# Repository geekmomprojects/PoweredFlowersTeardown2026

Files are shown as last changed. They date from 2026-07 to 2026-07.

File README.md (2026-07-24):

# PoweredFlowersTeardown2026

Instructions for the BedazzLED Wearables workshop at Teardown 2026

 

## Hot Glue LED string layout

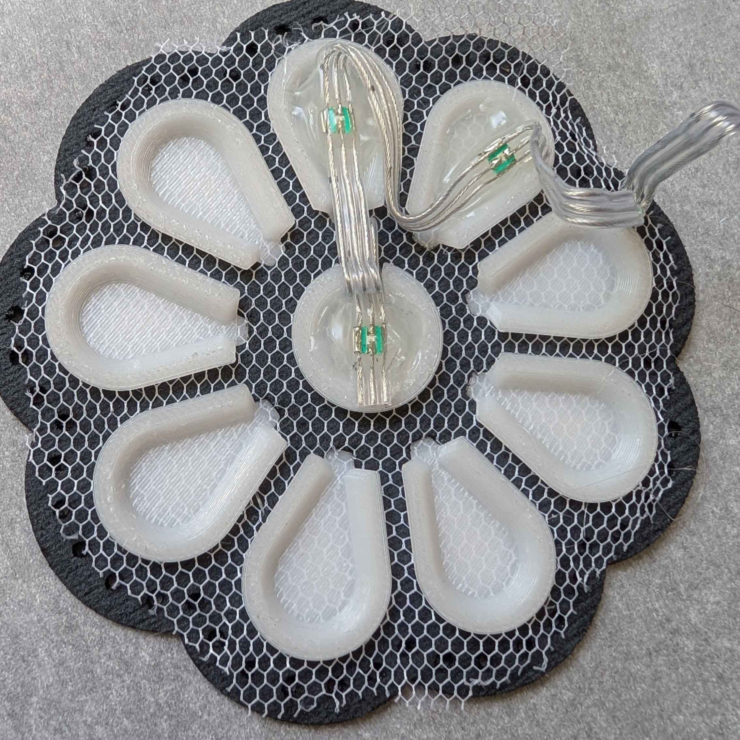
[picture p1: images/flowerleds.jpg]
 <br><br>
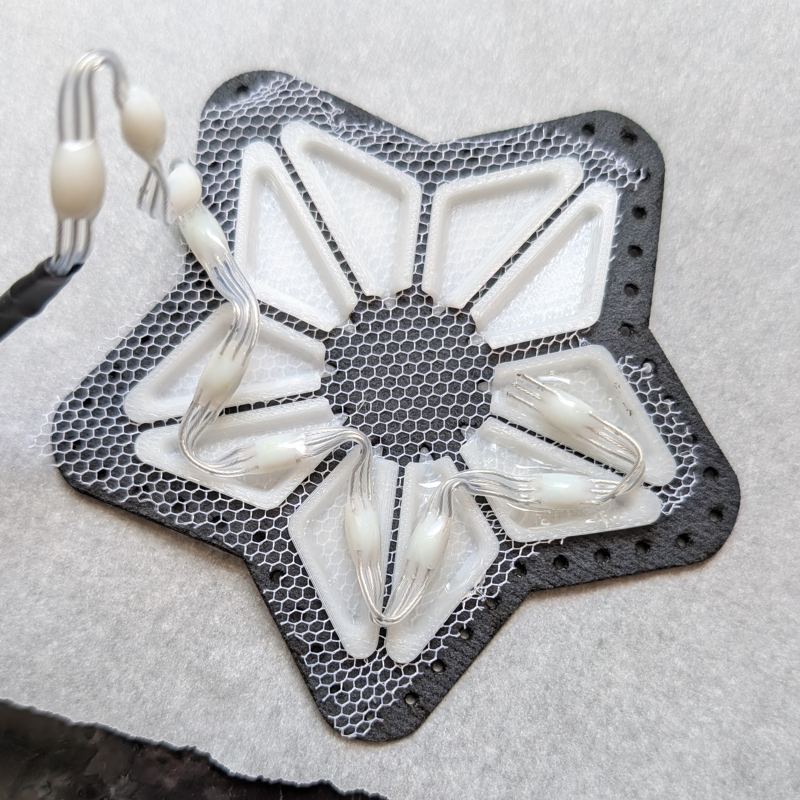
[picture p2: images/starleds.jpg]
 <br><br>
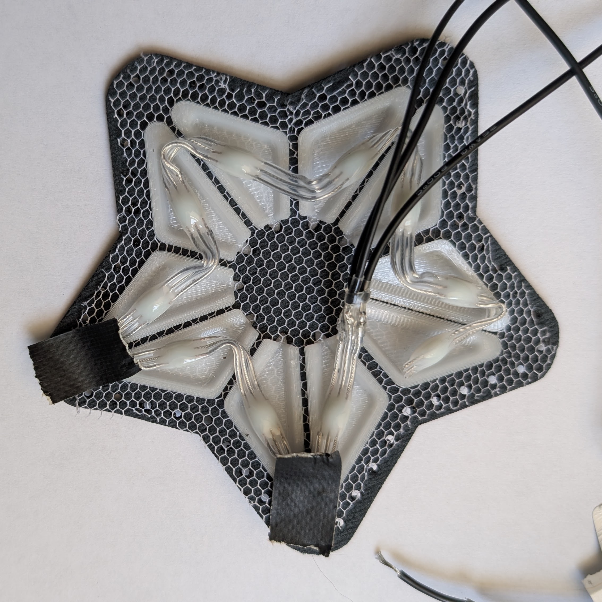
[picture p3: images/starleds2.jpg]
 <br><br>

## Microphone Soldering:

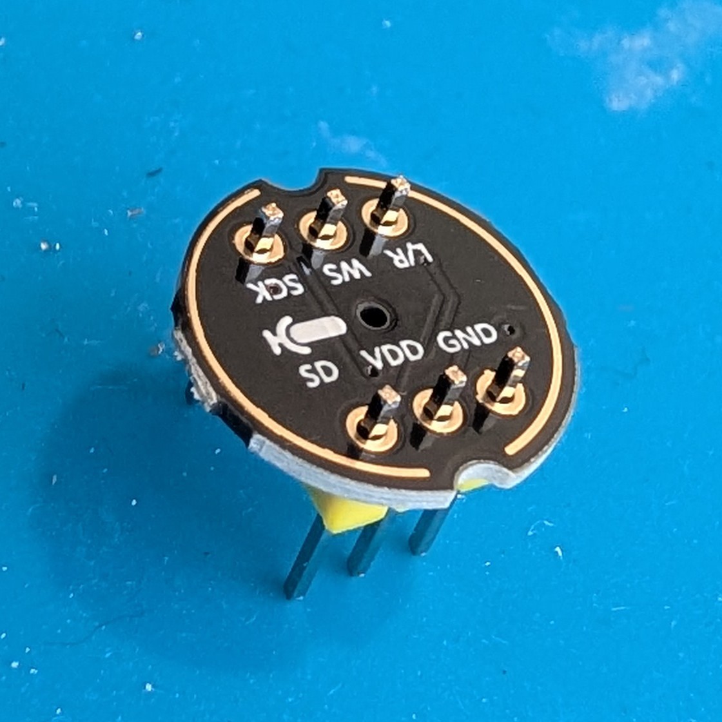
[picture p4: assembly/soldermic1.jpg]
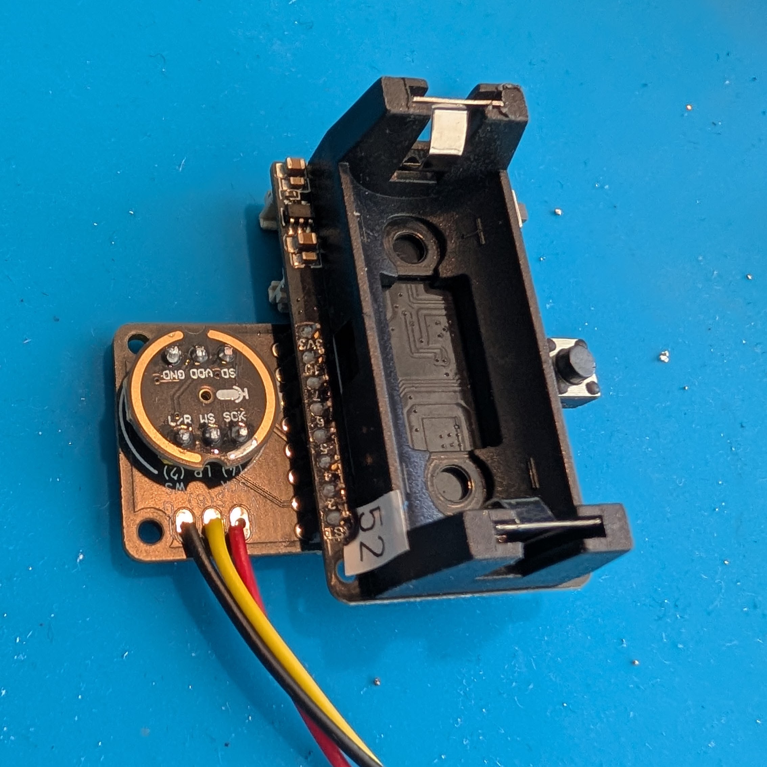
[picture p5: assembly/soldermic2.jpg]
  <br><br>

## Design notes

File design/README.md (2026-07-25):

## Design files for 3D printed star and flower diffusers + outlines for faux leather covers <BR><BR>

### 3D Printed Diffuser Array
- Print diffusers out of translucent PETG (ideally) filament. I like to use [California Filament Cloudy White](https://californiafilament.com/products/cloudy-white-petg-filament-1).
- Stop the printafter *2.4 mm* and add a layer of tulle or mesh (mosquito netting works well) before completing the print. The flat faces of the diffusers should rest against the print bed.
- For best outcome with the sloped sides around the indentation where the faux leather cover is seated, use an adaptive layer height setting if your slicer supports it, or use a small enough layer height that overhangs aren't a problem.

### Laser Cut Faux Leather Cover
- Laser cut the covers from laserable leatherette or any other flexible, laser cuttable material
- Houston acrylic has a [nice selection of intersting faux leather fabric](https://houstonacrylic.com/collections/leatherette)

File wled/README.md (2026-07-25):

# WLED links and configuration files

Find the access point for your board - default name is **WEAR-WLEDXX** where **XX** is the one or two digit number on the sticker on the board. The default password is **wled1234**. Connecting to it should bring up a captive portal with the control web page, but if not, open a browser and go to IP address **4.3.2.1** in the address bar.

- The ESP32s we used are pre-flashed, using the installer at [WLED Installation Website](https://wled-install.github.io/), with the **Nightly Build 16.x branch** version, and the **ESP32 C3 4MB Flash with Audio Reactive Usermod** option under that version
-  JSON files for installing the presets and configurations are included in this directory. These can be imported directly into WLED from the Security configuration paged and set up WLED.
- Hardware Configuration
  - 10 WS2812 LEDs on **pin 8**
  - push button on **pin 9**
  - I2S microphone IMNP441
     - SCK **pin 4**
     - WS **pin 2**
     - SD **pin 5**
     - L/R connected to GND

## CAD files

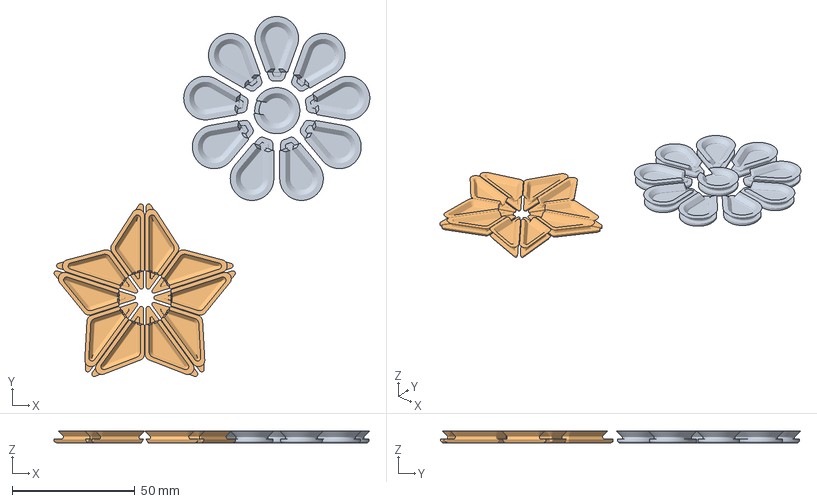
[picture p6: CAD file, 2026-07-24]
design/StarAndHeartPrintFile.3mf
128.7 x 146.8 x 4.80 mm
FlowerMesh.stl
StarMesh.stl

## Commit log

2026-07-24 Add design instructions for diffusers and covers
    Includes instructions for 3D printed diffusers and laser cut covers.
2026-07-24 Add images for powered flower workshop
2026-07-24 Add README for powered flowers workshop images
2026-07-24 Add README with powered flower assembly photos
2026-07-24 Add Microphone Soldering section to README
    Added section for Microphone Soldering with images.
2026-07-24 Fix image paths for microphone soldering section
2026-07-24 Add Hot Glue LED string layout to README
    Added section for Hot Glue LED string layout with images.
2026-07-25 Revise diffuser printing instructions in README
    Updated printing instructions for diffusers and added tips for optimal results.
2026-07-25 Revise README with detailed design instructions
    Added detailed sections for 3D printed diffusers and laser cut covers.
